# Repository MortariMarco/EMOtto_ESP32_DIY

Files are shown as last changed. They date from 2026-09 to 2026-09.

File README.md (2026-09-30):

# EMOtto ESP32 DIY — firmware 2.0

Robot project by Marco Mortari, for a classic ESP32 with Bluetooth Serial, GC9A01 display, four SG90 servos, two TTP223 touch sensors, VL53L0X and DFPlayer Mini.

Project and printable parts: https://www.printables.com/model/1362284-emotto_esp32-diy

## Start here

1. Download and extract the repository.
2. Install the Espressif ESP32 board support in Arduino IDE and select the board matching your classic ESP32.
3. Close Arduino IDE. Copy `Librerie/EMOttoDIYLib` and `Librerie/TFT_eSPI` into your Arduino sketchbook's `libraries` directory. Each copied folder must contain `library.properties` directly. Reopen Arduino IDE.
4. Install ESP32Servo, Adafruit GFX Library, Adafruit VL53L0X and DFRobotDFPlayerMini through Library Manager, including their dependencies.
5. Open **`Firmware/EMOttoESP32_2_0/EMOttoESP32_2_0.ino`**. Verify and upload. This is the full firmware; do not use the simplified Bluetooth example inside the library.
6. Install `App/EMOttoController_3_0.apk` on Android, pair the robot named `EMOtto`, and select it in the app.

Read [the Italian installation guide and pinout](LEGGIMI.md) before connecting or powering the robot.

## Included files

- Full Arduino firmware: `Firmware/EMOttoESP32_2_0/`.
- Original EMOttoDIYLib 1.0.0 and configured TFT_eSPI 2.5.43: `Librerie/`.
- Android APK and editable MIT App Inventor `.aia` source: `App/`.
- Audio files: `MicroSD/mp3/`.
- Wiring diagrams: `Collegamenti/`.
- Printable parts and documentation: see the corresponding folders.

The supplied TFT_eSPI is configured for GC9A01: MOSI 23, SCLK 18, CS 5, DC 17, RST 16, with TFT_BL 22 disabled. Avoid replacing it with a differently configured copy.

## App source

Import `App/EMOttoController_3_0.aia` into MIT App Inventor using Projects > Import project (.aia) from my computer. The Build menu can generate an Android APK. The `.aia` file is source code, not an installable app.

## Audio exclusions

Tracks **4, 31, 35, 36 and 37** are not distributed for copyright reasons. Do not renumber the remaining files. Use only audio you have the rights to use when completing your own microSD.

The original firmware uses DFPlayer `play(number)`, which selects a track index. Missing files or copy order can affect which sound is played; verify the mapping on your microSD. See `Documentazione/Audio_inclusi.csv` and the Italian guide.

## Verification status

This distribution preserves the supplied firmware and library sources. Archive integrity and the presence of the App Inventor project components were checked. No ESP32 compilation, app rebuild or hardware test was performed while preparing this package. Tested board/core/dependency versions are not recorded in the supplied archive; the author checklist is in `Documentazione/Verifica_autore.md`.

## Credits and licenses

EMOtto project by Marco Mortari. The custom library derives from Otto DIY; original library license files are preserved in their respective folders. The project credits Camilo Parra Palacio, Scotty Franzyshen and ElectronBot EMO. Components retain their respective licenses; this repository does not introduce one blanket license for all firmware, app, models and audio.

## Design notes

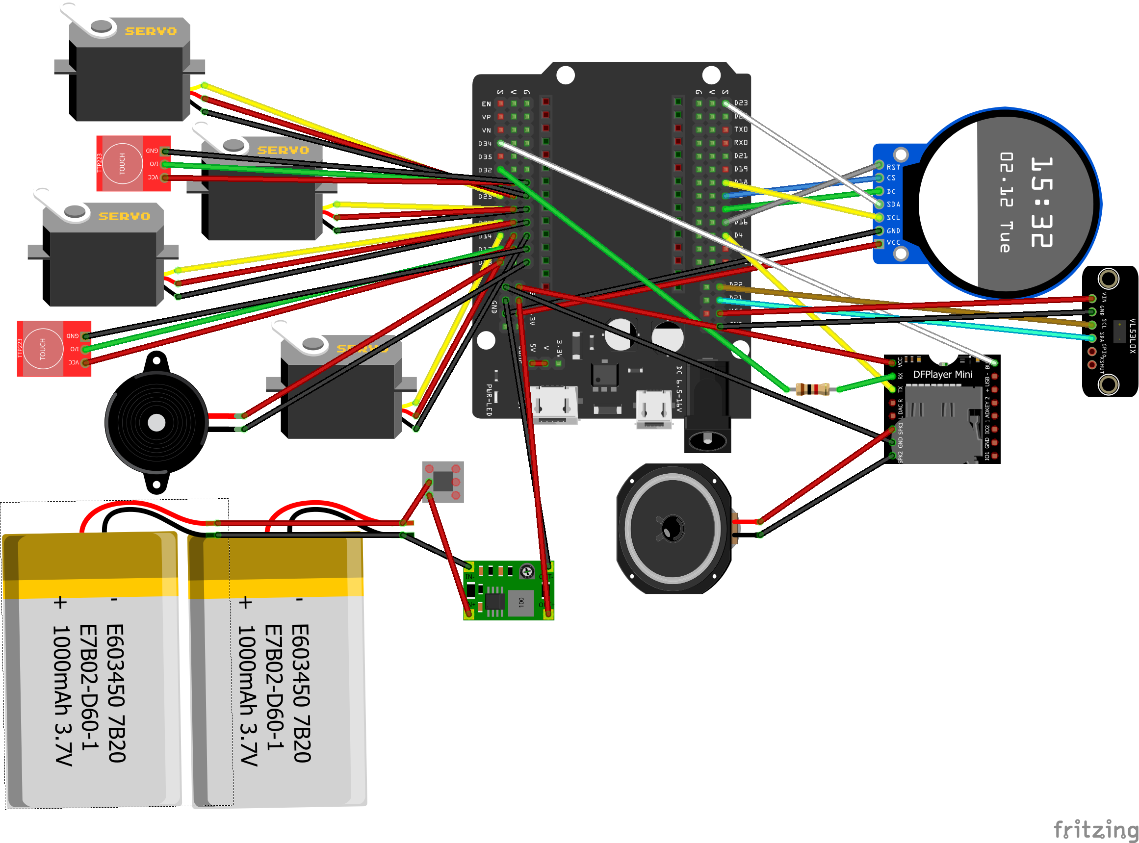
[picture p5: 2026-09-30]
Collegamenti/EMOtto_32_bb.png

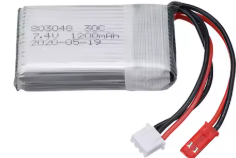
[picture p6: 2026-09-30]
Collegamenti/Battery 7,4V 1200mAh.png

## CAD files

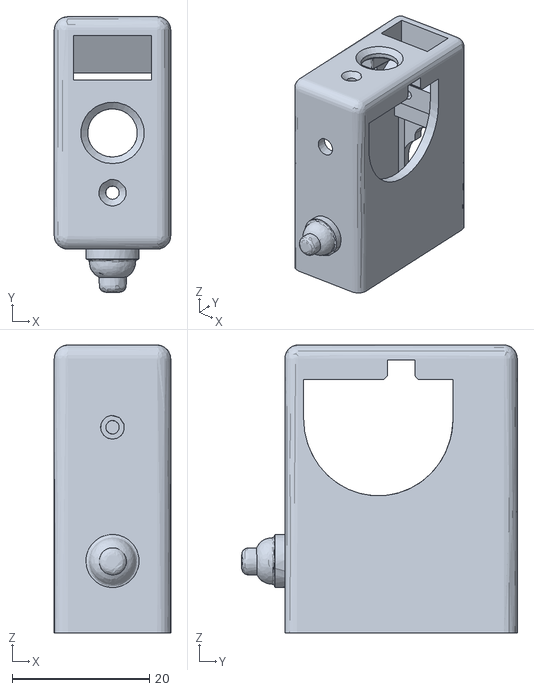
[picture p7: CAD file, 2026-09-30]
STL/EMOtto 2.0 ESP32_Leg.stl
17.0 x 40.2 x 42.0

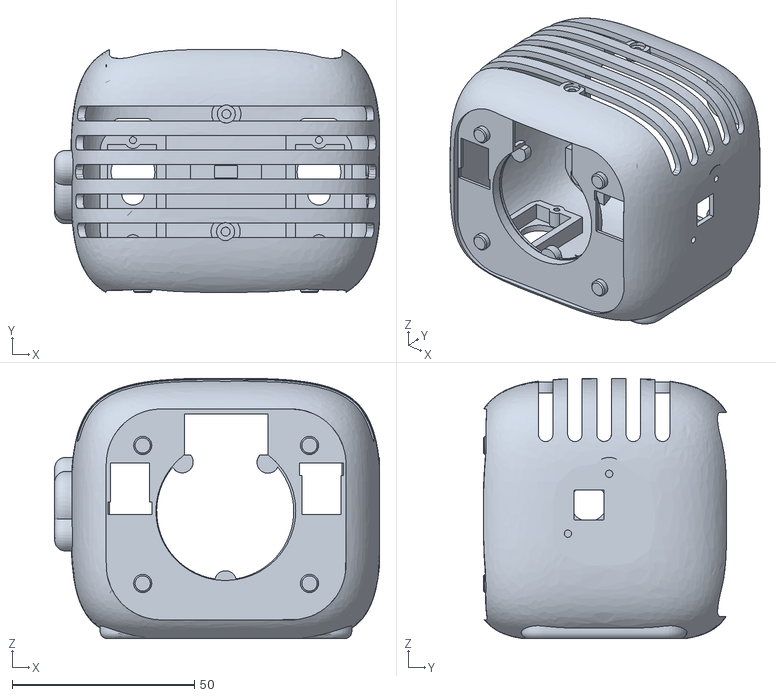
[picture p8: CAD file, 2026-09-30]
STL/EMOtto 2.0 ESP32_Head.stl
89.1 x 66.7 x 71.4

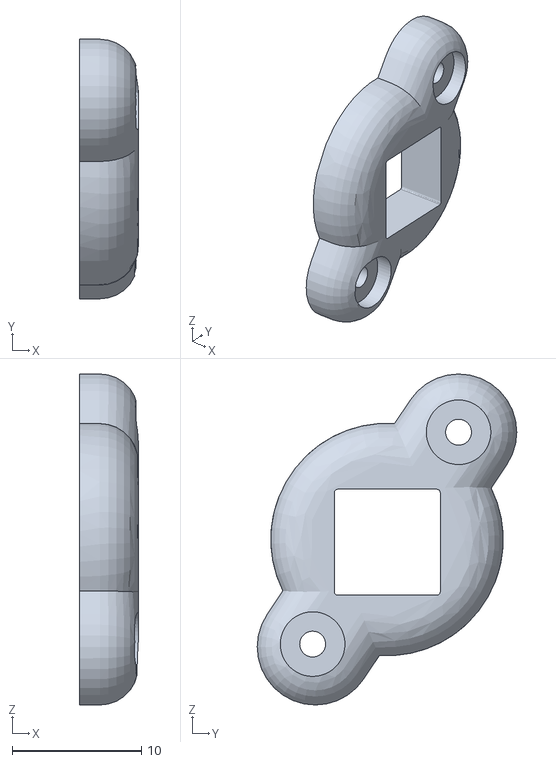
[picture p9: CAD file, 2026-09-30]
STL/EMOtto 2.0 ESP32_earswitch.stl
4.57 x 20.1 x 25.6

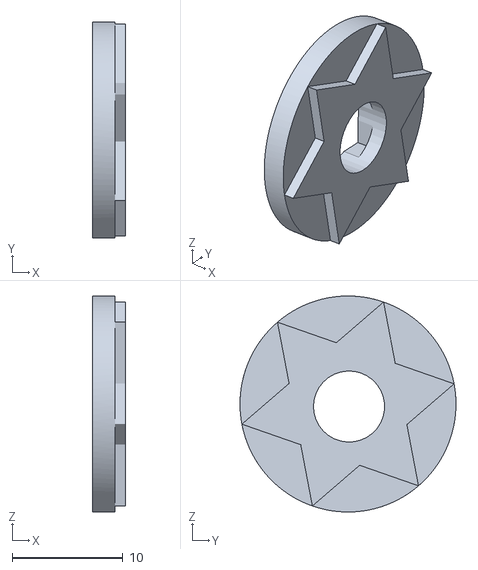
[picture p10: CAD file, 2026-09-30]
STL/EMOtto 2.0 ESP32_CoverEarSwitch.stl
3.01 x 19.5 x 19.5

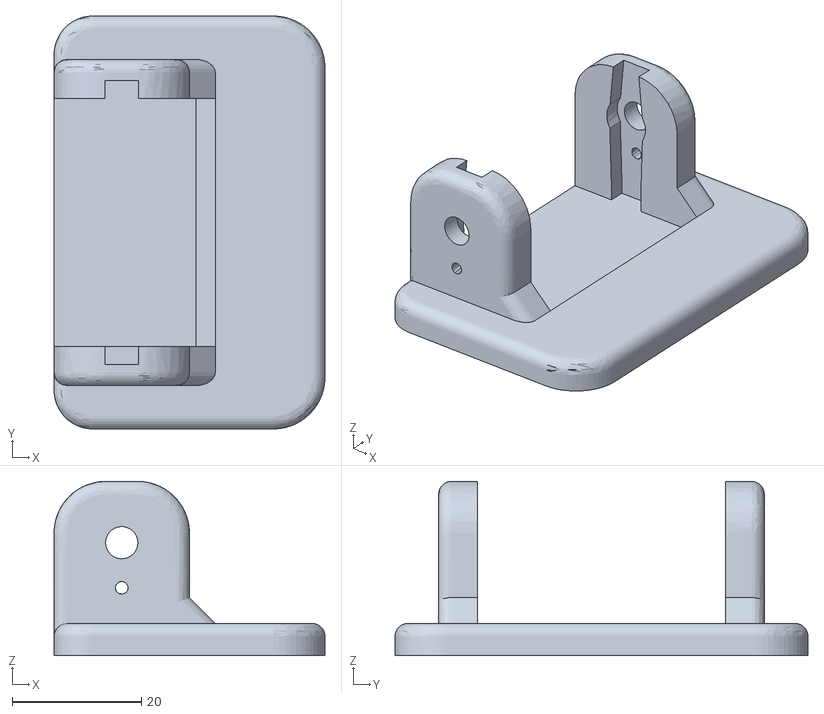
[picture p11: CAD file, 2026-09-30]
STL/EMOtto 2.0 ESP32_LeftFoot.stl
42.0 x 64.0 x 27.0

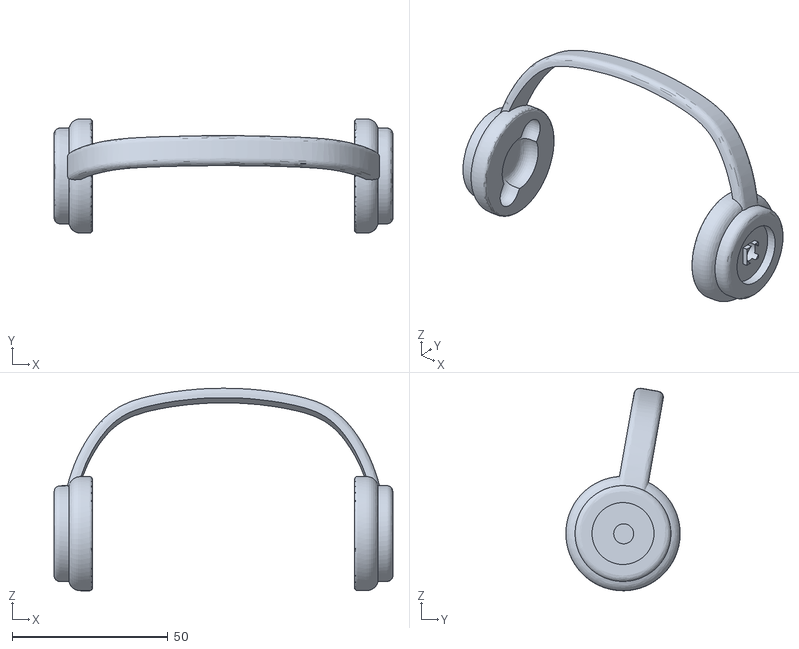
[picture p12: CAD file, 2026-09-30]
STL/EMOtto 2.0 ESP32_earphones.stl
108.8 x 36.7 x 65.0

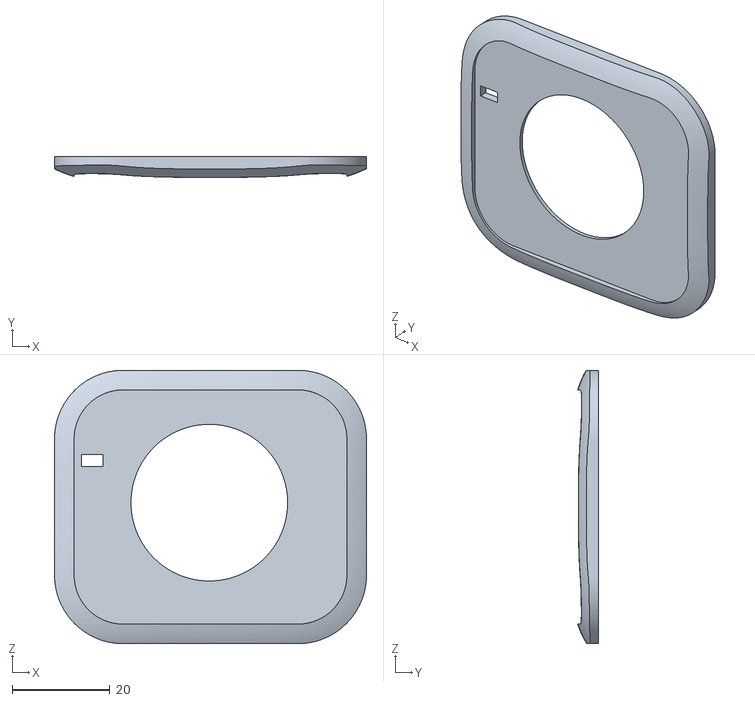
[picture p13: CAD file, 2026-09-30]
STL/EMOtto 2.0 ESP32_Front.stl
63.7 x 4.24 x 55.8

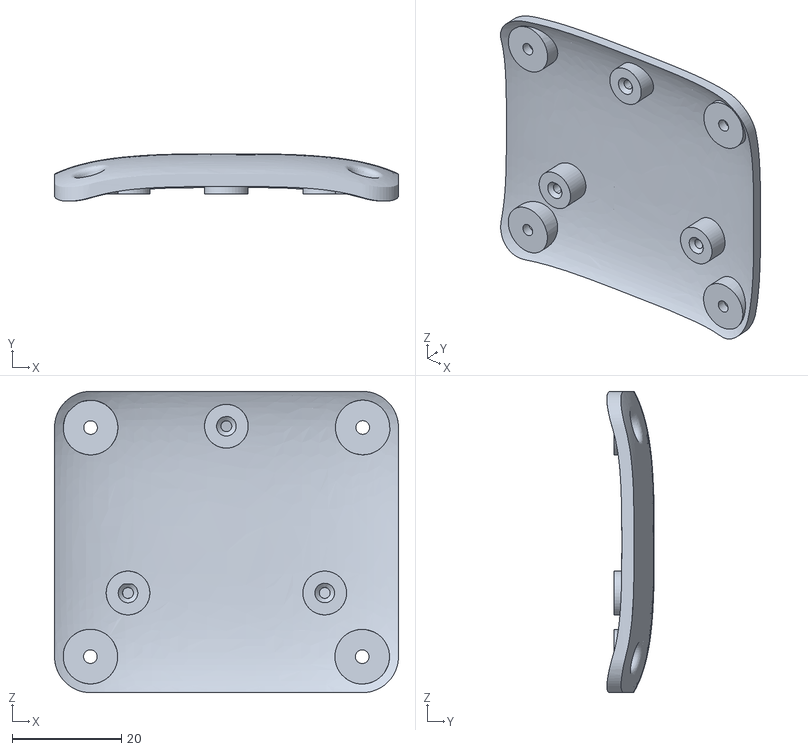
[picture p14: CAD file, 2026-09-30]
STL/EMOtto 2.0 ESP32_Back.stl
63.0 x 8.68 x 55.1

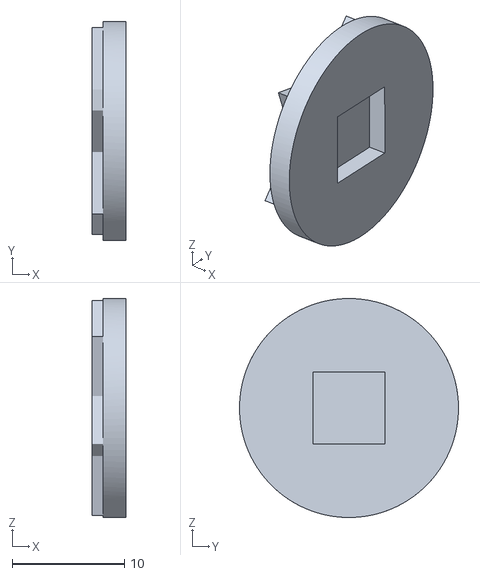
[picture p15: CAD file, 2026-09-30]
STL/EMOtto 2.0 ESP32_EarCover.stl
3.01 x 19.5 x 19.5

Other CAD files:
STL/EMOtto 2.0 ESP32_RightFoot.stl

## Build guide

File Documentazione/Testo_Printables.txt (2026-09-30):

EMOtto ESP32 2.0 — programma, librerie, app e file per il montaggio.

Estrarre lo ZIP e leggere LEGGIMI.md. Lo sketch da aprire è Firmware/EMOttoESP32_2_0/EMOttoESP32_2_0.ino. Nella distribuzione Printables scaricare EMOttoDIYLib.zip e TFT_eSPI.zip dagli allegati separati; nella distribuzione GitHub usare le cartelle Librerie. Installare le due librerie, quindi le dipendenze indicate nelle istruzioni. Nella cartella App sono inclusi l’APK da installare su Android e il progetto sorgente .aia da importare in MIT App Inventor per modificare l’app.

Le tracce musicali 4, 31, 35, 36 e 37 non sono distribuite per copyright. Per completare quelle funzioni usare personalmente audio di cui si possiedono i diritti, mantenendo gli abbinamenti del programma. Il firmware originale usa gli indici del DFPlayer: controllare l'ordine effettivo sulla microSD.

Sono inclusi schema dei collegamenti e STL. Scheda/versioni e risultati della prova sul robot devono essere riportati dall'autore prima di dichiarare questa distribuzione testata.

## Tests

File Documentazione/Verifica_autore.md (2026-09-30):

# Controlli per l'autore prima della pubblicazione

- Firmware, app, modelli, audio e librerie sono estratti dall'archivio fornito. Nessuna modifica ai sorgenti.
- Versioni di prova, vecchia OttoDIYLib, esempi semplificati, video, PSD e file duplicati non sono inclusi.
- EMOttoDIYLib 1.0.0 e TFT_eSPI 2.5.43 sono le copie originali.
- La libreria originale conserva il vecchio esempio Bluetooth: le istruzioni indicano esplicitamente di aprire il firmware principale, non quell'esempio.
- Le tracce 4, 31, 35, 36, 37 non sono incluse. play(numero) dipende dall'indice del DFPlayer: verificare gli abbinamenti audio e completare la microSD privata prima di dichiarare tutti i balli/canti funzionanti.
- Nello setup originale performExpression(EXP_NORMAL) chiama forceHome() prima di Otto.init(). Questo ordine è stato preservato per rispettare la richiesta di non cambiare il programma: verificare l'avvio sul robot; se occorre correggerlo, spostare l'espressione iniziale dopo Otto.init().
- Senza il VL53L0X rilevato lo setup entra in while(1): il sensore fa parte della configurazione richiesta.
- Incluso il progetto App Inventor .aia: archivio integro, Screen1 e blocchi Bluetooth presenti, asset grafici richiamati disponibili. Il progetto non è stato compilato; non è certificata la corrispondenza binaria con l’APK. Provare i pulsanti sul robot.
- Alcuni testi dei pulsanti nell’AIA includono i comandi `(`, `)` e `/`, che non hanno un case dedicato nel gestore Bluetooth della libreria. Questi controlli vanno verificati; app e firmware sono stati mantenuti come forniti.
- Le versioni esatte del core e delle dipendenze non sono registrate nell'archivio. Completare i dati qui sotto dopo la prova.

Scheda: ____________________
Arduino IDE: _______________
Core ESP32: ________________
ESP32Servo: ________________
Adafruit GFX: _____________
Adafruit VL53L0X: __________
DFRobotDFPlayerMini: _______
Data e risultato prova: ____

Aggiornamento del pacchetto: rimossi dall’elenco audio anche 0004 e 0036, aggiunto il progetto .aia alla documentazione. Il pacchetto contiene 32 file MP3. Nessuna modifica a firmware, librerie o sorgenti dell’app.

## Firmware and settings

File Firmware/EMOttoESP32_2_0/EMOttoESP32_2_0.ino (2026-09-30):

/// ---- EMOtto_ESP32_30pin + shield ver 2.0 ----- //
// ---- by Marco Mortari ---- //
// ---- ver 2.0 08/07/2025---- //
// ----  By Daddy for Francesco's Birthday 9 years---- //
// ---- Library EMOttoDIYLib 1.0.0 (OttoDIYLib 13.0.0.modificata)  ---- //
//--
//---------------------------------------------------------
// ---- Component  ---- //
// ---- 4 Servo SG90  180 Degrees ---- //
// ----  Round Display  GC9A01  ---- //
// ----  Passive Buzzer  ---- //
// ----  Touch Capacitive TTP223 * 2 ---- //
// ----  6 pin switch  ---- //
// ----  UBEC 5V 3A  ---- //
// ----  Battery 7.4V  ---- //
// ----  Sensor VL53L0X  ---- //
// ----  DFPlayer Mini  ---- //


//-- First step: Make sure the pins for servos are in the right position 
/*               -------- 
                |  (  )  |
                |--------|
 RIGHT LEG 26   |        | LEFT LEG 25
                 -------- 
                ||      ||
RIGHT FOOT 14 |---      ---| LEFT FOOT 27  
*/

// ----  GC9A01A LIBRERIA TFT_SPI SETUP200 CS=5 DC=17 RST= 16 SCLK=18 SDA(MOSI)=23 COMMENT BL=22---- //

// --- .ino
#include <EMOtto.h>
Otto Otto;  // This is Otto!
#include <TFT_eSPI.h>
#include <SPI.h>
#include "expressions.h"
#include "modes.h"
#include "sleep.h"
#include "draw_utils.h"
#include "colors.h"
#include "BluetoothCommands.h"
#include "BluetoothSerial.h"
#include <Adafruit_VL53L0X.h>
#include <DFRobotDFPlayerMini.h>
#include <modes.h>
#include "dance.h"
#include "dance2.h"
#include "dance3.h"
#include "dance4.h"

HardwareSerial mySerial(2);  // Serial2
BluetoothSerial SerialBT;
TFT_eSPI tft = TFT_eSPI(); // Usa impostazioni da User_Setup.h
Adafruit_VL53L0X lox = Adafruit_VL53L0X();
DFRobotDFPlayerMini myDFPlayer;

#define LeftLeg 25
#define RightLeg 26
#define LeftFoot 27
#define RightFoot 14
#define Buzzer 13
#define TOUCH_PIN_1 12  // Primo touch: cicla le emozioni
#define TOUCH_PIN_2 33  // Secondo touch: cambia modalità
// VL53L0X SCL=22
// VL53L0X SDA=21
//DFPlayer Mini su Serial2
// GPIO 32 (RX)
// GPIO 4 (TX)
//--- canzoni mp3 
// ─── DF-Player ────────────────────────────────────────────────────────────────
#define DF_BUSY_PIN     34          // indica che mp3 non e finito
bool  wasPlaying = false;           // stato precedente del BUSY (LOW = suona)
inline bool isPlaying() {           // helper: true quando il DFPlayer riproduce
return digitalRead(DF_BUSY_PIN) == LOW;
}

// --- STATO TOUCH --- //
bool touch1WasPressed = false;  // stato touch nel ciclo precedente TOUCH 1
bool touch2WasPressed = false;  // stato touch nel ciclo precedente TOUCH 2

// === PROTOTIPI delle funzioni ===
void drawExpression(int type);
void animateBlink();
void performExpression(int type);
void drawDance();
void dfPlay(uint16_t n) {         
  myDFPlayer.play(n);
}
// --- modalita operative --- //
const int totalModes = MODE_TOTAL;
ModeType currentMode = MODE_EMOTIONS;  // inizializza a modalità emotions
// Stato precedente dei touch
bool lastTouch1Pressed = false;
bool lastTouch2Pressed = false;
static unsigned long touchStartTime = 0;
static unsigned long lastTouch2Time = 0;
static unsigned long lastTouch1Time = 0;
const unsigned long debounceDelay = 150;  
// --- espressioni
ExpressionType expression = EXP_NORMAL;
const int totalExpressions = EXP_TOTAL - 1; 
ExpressionType lastExpression = EXP_NORMAL;
//---- pupille
int pupilOffsetX = 0;
int pupilOffsetY = 0;
//---palpebre---//
unsigned long lastBlinkTime = 0;
unsigned long blinkInterval = 4000;  // ogni quanti ms far partire un blink spontaneo
bool isBlinking = false;
int blinkStep = 0;
// ---- ADDORMENTAMENTO  ----//
unsigned long sleepTimeout = 90000;  // 90 secondi DOPO QUANTO SI ADDORMENTA
unsigned long lastActivityTime = 0;
bool isSleeping = false;
SleepState sleepState = SLEEP_START;
unsigned long sleepTimer = 0;
int breathRadius = 8;
int zCount = 0;
//----lacrime ----//
// Variabili per animazione lacrime con esplosione
int tearY = 122;
int tearStartY = 122;
int tearEndY = 160;
unsigned long lastTearTime = 0;
int tearSpeed = 50;
bool tearJustStarted = true;
bool tearVisible = true;
bool tearExploding = false;
int explosionStep = 0;
int maxExplosionSteps = 4;
// --lacrimuccia
bool yawnRunning = false;     // indica se l’animazione sbadiglio è in corso
unsigned long yawnStartTime = 0;
int yawnPhase = 0;            // fasi dell’animazione sbadiglio
bool yawnTearActive = false;
int yawnTearY = 0;
unsigned long lastYawnTearUpdate = 0;
// -- battiti cuore --//
// Impostazioni animazione battito cuore
unsigned long lastHeartbeatTime = 0;
int heartbeatIndex = 0;
int heartbeatSizes[] = { 12, 16, 14, 13, 12 };      // battito veloce poi lento
int heartbeatDelays[] = { 50, 80, 120, 150, 200 };  // ritmi variabili
int numHeartbeatFrames = sizeof(heartbeatSizes) / sizeof(int);
bool isInLove = false;           // controlla se animare
// --- bluetooth --- ///
bool wasConnected = false;
bool lastBluetoothState = false;
static bool wasSleepingConnected = false;
// --- DANCE background ---
static uint32_t lastDanceBgTime = 0;
const uint32_t danceBgInterval = 300;   // ms cambio colore
// --- cantando
unsigned long lastFootMoveTime = 0;
bool footDown = false;
unsigned long footInterval = 600;  // battito ogni 600 ms (~100 BPM)
int currentSong = -1;
bool songStarted = false;
int lastSongPlayed = -1;
int MP3_MIN = 31;
int MP3_MAX = 34;
bool singerIntroDone = false;
unsigned long singerIntroStart = 0;
enum SingerState { INTRO_29, BASE_30, MAIN_SONG };
SingerState singerState = INTRO_29;
extern ModeType       currentMode;
extern ExpressionType lastExpression;
ModeType lastPrintedMode = static_cast<ModeType>(-1);
// balli
extern bool dance2Active ;
extern bool musicFinished ;
extern bool musicStarted ;
extern bool dance3Active ;
extern bool music3Finished ;
extern bool music3Started ;
extern bool dance4Active ;
extern bool music4Finished ;
extern bool music4Started ;
// --- Volume dfplayer 
int currentVolume = 25;
// velocita iniziale
int walkSpeed = 1000;

void setup() {
  Serial.begin(115200);  
  tft.init();
  tft.setRotation(2);
   performExpression(EXP_NORMAL);   // volto iniziale 
  lastExpression = EXP_NORMAL;
 // --- CANTANTE
 //initMusicalNotes();
  // Inizializza I2C sui pin specifici
  Wire.begin(21, 22);  // SDA = 21, SCL = 22
  if (!lox.begin()) {
    Serial.println("VL53L0X non trovato!");
    while (1);
  }
  Serial.println("VL53L0X pronto");
  randomSeed(micros());
  lastActivityTime = millis();
  Otto.init(LeftLeg, RightLeg, LeftFoot, RightFoot, true, Buzzer);
  Otto.sing(S_connection);
  // --- Bluetooth  ----//
  SerialBT.begin("EMOtto");
  Serial.println("Bluetooth avviato. Ora puoi accoppiare!");
  // ----- DFPlayer Mini ---- //
  // Avvia Serial2 su GPIO 32 (RX), GPIO 4 (TX)
  mySerial.begin(9600, SERIAL_8N1, 32, 4);
  if (!myDFPlayer.begin(mySerial)) {
    Serial.println(" DFPlayer non trovato! Disabilitato.");
  } else {
    Serial.println("✅ DFPlayer inizializzato correttamente.");
    myDFPlayer.volume(currentVolume);
    delay(500);  // piccolo delay per sicurezza
      myDFPlayer.EQ(DFPLAYER_EQ_NORMAL);
    myDFPlayer.play(1);
  }
  pinMode(TOUCH_PIN_1, INPUT_PULLDOWN);
  touch1WasPressed = digitalRead(TOUCH_PIN_1) == HIGH;
  pinMode(TOUCH_PIN_2, INPUT);
  touch2WasPressed = digitalRead(TOUCH_PIN_2) == HIGH;
  pinMode(DF_BUSY_PIN, INPUT_PULLUP);   // BUSY: HIGH = fermo, LOW = suona
  forceHome();
  // velocita iniziale
   walkSpeed = 1000;
   // Stati bluetooth
//    SerialBT.print("SPD:");
// SerialBT.println(walkSpeed);

// SerialBT.print("VOL:");
// SerialBT.println(currentVolume);

}

void loop() {
  unsigned long now = millis();
  bool touch1Pressed = digitalRead(TOUCH_PIN_1) == HIGH;
  bool touch2Pressed = digitalRead(TOUCH_PIN_2) == HIGH;
  // --- SLEEP MODE ---
  if (isSleeping) {
    updateSleepingAnimation();
    if ((touch1Pressed || touch2Pressed) && !touch1WasPressed && !touch2WasPressed) {
      touchStartTime = now;
    }
    if (!(touch1Pressed || touch2Pressed) && (touch1WasPressed || touch2WasPressed)) {
      wakeUp();
    }
    //  Risveglio tramite connessione Bluetooth
    if (SerialBT.connected()) {
      wakeUp();
    }
   touch1WasPressed = touch1Pressed;
   touch2WasPressed = touch2Pressed;
     return;
  }
  // --- ENTRA IN SLEEP SE INATTIVO ma solo se è in modalita emotions---
  if (!isSleeping
      && (now - lastActivityTime > sleepTimeout)
      && currentMode != MODE_AVOID
      && currentMode != MODE_FOLLOW
      && currentMode != MODE_DANCE
      && currentMode != MODE_SINGER
      && !SerialBT.hasClient()) {
    Serial.println(">> Condizione SLEEP soddisfatta");
    enterSleepMode();
    return;
  }
  // --- GESTIONE TOUCH 1: cambio espressione solo in modalità emozioni ---
  if (touch1Pressed && !touch1WasPressed && !isBlinking && currentMode == MODE_EMOTIONS && (now - lastTouch1Time > debounceDelay)) {
    lastTouch1Time = now;
    ExpressionType next = static_cast<ExpressionType>((expression + 1) % (totalExpressions + 1));
    Otto.sing(S_buttonPushed);
    performExpression(next);      // disegna + audio + movimento
    lastExpression   = next;
    lastActivityTime = now;
  }
  // --- GESTIONE TOUCH 2: cambio modalità ---
  if (touch2Pressed && !touch2WasPressed && (now - lastTouch2Time > debounceDelay)) {
    lastTouch2Time = now;
   if (currentMode == MODE_SINGER) {          // stop “d’emergenza”
    Serial.println(F(">> TOUCH2: esco da SINGER"));
    exitSingerMode(); 
    return;                                   // fine loop, niente altro da fare
  }
   if (currentMode == MODE_DANCE) {
        Serial.println(">> TOUCH2 premuto: fermo musica e movimenti (da DANCE)");
        myDFPlayer.stop();
        Otto.home();
        stopDance();
        songStarted = false;
        // 🔁 PASSA ALLA MODALITÀ SINGER
        currentMode = MODE_SINGER;
        lastExpression = EXP_NONE;
        Serial.println("Passo a modalità SINGER");
        return;
    }
    // Modalità normali: scorre ciclicamente
  /* --- ciclo modalità (EMOTIONS→…→SINGER→EMOTIONS) --- */
 currentMode = static_cast<ModeType>((currentMode + 1) % MODE_TOTAL);
    Serial.print(F(">> Cambio modalità: "));
    Serial.println(currentMode);
    // aggiorna stampa modalità subito dopo il cambio (opzionale)
    lastPrintedMode = static_cast<ModeType>(-1); // forza ristampa
   return;
}
  // --- STAMPA MODALITÀ SOLO SE CAMBIATA ---
  if (currentMode != lastPrintedMode) {
    switch (currentMode) {
      case MODE_AVOID: Serial.println("AVOID"); break;
      case MODE_FOLLOW: Serial.println("FOLLOW"); break;
      case MODE_DANCE: Serial.println("DANCE"); break;
      case MODE_SINGER: Serial.println("SINGER"); break;
      case MODE_EMOTIONS: Serial.println("EMOTIONS"); break;
    }
    lastPrintedMode = currentMode;
  }
  //  lastActivityTime = now;
  // Aggiorna stato precedente TOCCHI
  touch1WasPressed = touch1Pressed;
  touch2WasPressed = touch2Pressed;
  // --- verifica accoppiamento bluetooth ---///
  bool currentlyConnected = SerialBT.hasClient();
  if (currentlyConnected && !wasConnected) {
    // Appena connesso
    Serial.println("✅ Bluetooth connesso!");
    showBluetoothOn(expression);  // Mostra icona on alla connessione
    myDFPlayer.play(13); //modalita bluetooth attivata 
  } else if (!currentlyConnected && wasConnected) {
    showBluetoothOff(expression);  // Mostra icona off alla connessione
    Serial.println("❌ Bluetooth disconnesso!");
 //   myDFPlayer.play(13); //modalita bluetooth disattivata 
  }
  wasConnected = currentlyConnected;

  // --- GESTIONE MODALITÀ ---
    switch (currentMode) {
    case MODE_AVOID:
      if (lastExpression != EXP_AVOID) {
        performExpression(EXP_AVOID);
        lastExpression = EXP_AVOID;
      }
      handleAvoidMode();
      break;
    case MODE_FOLLOW:
      if (lastExpression != EXP_FOLLOW && !isBlinking) {
        performExpression(EXP_FOLLOW);
        lastExpression = EXP_FOLLOW;
      }
      handleFollowMode();
      break;
    case MODE_DANCE:
      if (currentMode != MODE_DANCE) break;  // Protezione extra
       if (lastExpression != EXP_DANCE && !isBlinking) {
        updateDance();      // gestisce passi
        performExpression(EXP_DANCE);   // Avvia danza
        lastExpression = EXP_DANCE;
 }
        updateDance();      // ballo attivo
        handleDanceMode();
        break; 
     case MODE_SINGER: {
   /* ── Primo ingresso ── */
       if (lastExpression != EXP_SINGER && !isBlinking) {
        performExpression(EXP_SINGER);      // faccina cantante
        lastExpression = EXP_SINGER;
        singerState = INTRO_29;
        startSingerFoot();                  // tuoi passi di ballo
        dfPlay(29);                         // intro vocale
  }
         drawSingingMouth();
         updateSingerFoot();
  /* ── Avanzamento stati con BUSY ── */
  switch (singerState) {
    case INTRO_29:
      if (!isPlaying() && wasPlaying) {     // 29 terminata
        dfPlay(30);                         // base musicale
        singerState = BASE_30;
      }
        break;

    case BASE_30:
      if (!isPlaying() && wasPlaying) {     // 30 terminata
        playRandomSong();                   // tua routine
        singerState = MAIN_SONG;
      }
      break;

    case MAIN_SONG:
      if (!isPlaying() && wasPlaying) {     // brano finito
        exitSingerMode();
      }
      break;
  }
  /* ── Salva stato BUSY per il prossimo loop ── */
  wasPlaying = isPlaying();
  break;
}
     case MODE_EMOTIONS:
       if (expression != lastExpression && !isBlinking) {
        performExpression(expression);
        lastExpression = expression;
  }
    break;
     default:
    break;
    }
   // --- ANIMAZIONE BLINK ---
  if (!isBlinking && (now - lastBlinkTime > blinkInterval)) {
    isBlinking = true;
    blinkStep = 0;
  }
  if (isBlinking) {
    animateBlink();
  }
  if ((expression == EXP_LOVE || expression == EXP_FOLLOW)   // ❤ anche in follow
    && !isBlinking
    && !isSleeping) {
    updateHeartEyes();
  }
  // --- ANIMAZIONE LACRIME ---
  if (expression == EXP_SAD && !isBlinking && !isSleeping) {
    updateTears();
  }
  // --- LACRIMUCCIA POST-SBADIGLIO ---
// Chiamare updateYawnAnimation() ogni ciclo
updateYawnAnimation();
// Chiamare updateYawnTear() per animazione lacrima
updateYawnTear();
// --- Sfondo cangiante mentre balla ---
if (expression == EXP_DANCE && millis() - lastDanceBgTime > danceBgInterval && !isBlinking) {
  tft.fillScreen(nextPastelColor());
    drawDance();
  lastDanceBgTime = millis();
}
 // --- riceve comandi bluetooth --- //
  handleBluetoothCommands(SerialBT, expression, currentMode, lastActivityTime);
  updateWalking();
 // richiamo balli
if (dance2Active) {
  updateDance2();
  updateMusic2Status();
}
  if (danceStep != STEP_NONE && !musicFinished) {
    updateDance();
  }
if (dance3Active) {
  updateDance3();
  updateMusic3Status();
}
if (dance4Active) {
  updateDance4();
  updateMusic4Status();
}

}
// --- Fine Loop --- //
// *******************  FUNZIONI DI SUPPORTO  ******************* //
void forceHome() {
  Otto.attachServos();
  int homes[4] = { 90, 90, 90, 90 };
  Otto._moveServos(500, homes);  // Muove forzatamente, bypassa Otto.home()
  delay(700);
  Otto.detachServos();
  Otto.setRestState(true);  // Mantieni coerenza col flag
}

void handleAvoidMode() {
  VL53L0X_RangingMeasurementData_t measure;
  lox.rangingTest(&measure, false);
  if (measure.RangeStatus != 4) {
    int distanza = measure.RangeMilliMeter;
    Serial.print("AVOID - Distanza: ");
    Serial.println(distanza);
  if (distanza < 150) {
    drawExpression(EXP_ANGRY);
      Otto.walk(2, 1000, -1);  // BACKWARD x2
      Otto.turn(3, 1000, 1);   // LEFT x3
    }
    Otto.walk(1, 1000, 1);  // FORWARD x1
  }
}

void handleFollowMode() {
  VL53L0X_RangingMeasurementData_t measure;
  lox.rangingTest(&measure, false);
  if (measure.RangeStatus != 4) {
    int distanza = measure.RangeMilliMeter;
    Serial.print("FOLLOW - Distanza: ");
    Serial.println(distanza);
  if (distanza > 180 && distanza < 600) {
      Otto.walk(1, 1000, 1);  // cammina avanti
    } else {
      //     Otto.stop();
      drawExpression(EXP_NORMAL);
    }
  }
}

void handleDanceMode() {
  // sfondo cangiante
  if (millis() - lastDanceBgTime > danceBgInterval && !isBlinking) {
        tft.fillScreen(nextPastelColor()); // sfondo nuovo
    drawDance();   
    lastDanceBgTime = millis();
  }
}

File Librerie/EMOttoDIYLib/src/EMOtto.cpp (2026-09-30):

#if defined(ARDUINO) && ARDUINO >= 100
  #include "Arduino.h"
#else
  #include "WProgram.h"
  #include <pins_arduino.h>
#endif
#include "EMOtto.h"
#include <Oscillator.h>

void Otto::init(int YL, int YR, int RL, int RR, bool load_calibration, int Buzzer) {

  servo_pins[0] = YL;
  servo_pins[1] = YR;
  servo_pins[2] = RL;
  servo_pins[3] = RR;

  attachServos();
  isOttoResting=false;

  if (load_calibration) {
    for (int i = 0; i < 4; i++) {
      int servo_trim = EEPROM.read(i);
      if (servo_trim > 128) servo_trim -= 256;
      servo[i].SetTrim(servo_trim);
    }
  }

  //Buzzer pin:
  pinBuzzer = Buzzer;
  pinMode(Buzzer,OUTPUT);
 
}
///////////////////////////////////////////////////////
void Otto::initMATRIX(int DIN, int CS, int CLK, int rotate){
ledmatrix.init( DIN, CS, CLK, 1, rotate);   // set up Matrix display
}
void Otto::matrixIntensity(int intensity){
ledmatrix.setIntensity(intensity);
}

///////////////////////////////////////////////////////////////////
//-- ATTACH & DETACH FUNCTIONS ----------------------------------//
///////////////////////////////////////////////////////////////////
void Otto::attachServos(){
    servo[0].attach(servo_pins[0]);
    servo[1].attach(servo_pins[1]);
    servo[2].attach(servo_pins[2]);
    servo[3].attach(servo_pins[3]);
}

void Otto::detachServos(){
    servo[0].detach();
    servo[1].detach();
    servo[2].detach();
    servo[3].detach();
}

///////////////////////////////////////////////////////////////////
//-- OSCILLATORS TRIMS ------------------------------------------//
///////////////////////////////////////////////////////////////////
void Otto::setTrims(int YL, int YR, int RL, int RR) {
  servo[0].SetTrim(YL);
  servo[1].SetTrim(YR);
  servo[2].SetTrim(RL);
  servo[3].SetTrim(RR);
}

void Otto::saveTrimsOnEEPROM() {

  for (int i = 0; i < 4; i++){
      EEPROM.write(i, servo[i].getTrim());
  }
}

///////////////////////////////////////////////////////////////////
//-- BASIC MOTION FUNCTIONS -------------------------------------//
///////////////////////////////////////////////////////////////////
void Otto::_moveServos(int time, int  servo_target[]) {

  attachServos();
  if(getRestState()==true){
        setRestState(false);
  }

  final_time =  millis() + time;
  if(time>10){
    for (int i = 0; i < 4; i++) increment[i] = (servo_target[i] - servo[i].getPosition()) / (time / 10.0);

    for (int iteration = 1; millis() < final_time; iteration++) {
      partial_time = millis() + 10;
      for (int i = 0; i < 4; i++) servo[i].SetPosition(servo[i].getPosition() + increment[i]);
      while (millis() < partial_time); //pause
    }
  }
  else{
    for (int i = 0; i < 4; i++) servo[i].SetPosition(servo_target[i]);
    while (millis() < final_time); //pause
  }

  // final adjustment to the target. if servo speed limiter is turned on, reaching to the goal may take longer than 
  // requested time.
  bool f = true;
  while(f) {
    f = false;
    for (int i = 0; i < 4; i++) {
      if (servo_target[i] != servo[i].getPosition()) {
        f = true;
        break;
      }
    }
    if (f) {
      for (int i = 0; i < 4; i++) {
        servo[i].SetPosition(servo_target[i]);
      }
      partial_time = millis() + 10;
      while (millis() < partial_time); //pause
    }
  };
}

void Otto::_moveSingle(int position, int servo_number) {
if (position > 180) position = 90;
if (position < 0) position = 90;
  attachServos();
  if(getRestState()==true){
        setRestState(false);
  }
int servoNumber = servo_number;
if (servoNumber == 0){
  servo[0].SetPosition(position);
}
if (servoNumber == 1){
  servo[1].SetPosition(position);
}
if (servoNumber == 2){
  servo[2].SetPosition(position);
}
if (servoNumber == 3){
  servo[3].SetPosition(position);
}
}

void Otto::oscillateServos(int A[4], int O[4], int T, double phase_diff[4], float cycle=1){

  for (int i=0; i<4; i++) {
    servo[i].SetO(O[i]);
    servo[i].SetA(A[i]);
    servo[i].SetT(T);
    servo[i].SetPh(phase_diff[i]);
  }
  double ref=millis();
   for (double x=ref; x<=T*cycle+ref; x=millis()){
     for (int i=0; i<4; i++){
        servo[i].refresh();
     }
  }
}

void Otto::_execute(int A[4], int O[4], int T, double phase_diff[4], float steps = 1.0){

  attachServos();
  if(getRestState()==true){
        setRestState(false);
  }


  int cycles=(int)steps;

  //-- Execute complete cycles
  if (cycles >= 1)
    for(int i = 0; i < cycles; i++)
      oscillateServos(A,O, T, phase_diff);

  //-- Execute the final not complete cycle
  oscillateServos(A,O, T, phase_diff,(float)steps-cycles);
}

///////////////////////////////////////////////////////////////////
//-- HOME = Otto at rest position -------------------------------//
///////////////////////////////////////////////////////////////////
void Otto::home(){

  if(isOttoResting==false){ //Go to rest position only if necessary

    int homes[4]={90, 90, 90, 90}; //All the servos at rest position
    _moveServos(500,homes);   //Move the servos in half a second

    detachServos();
    isOttoResting=true;
  }
}

bool Otto::getRestState(){
    return isOttoResting;
}

void Otto::setRestState(bool state){

    isOttoResting = state;
}

///////////////////////////////////////////////////////////////////
//-- PREDETERMINED MOTION SEQUENCES -----------------------------//
///////////////////////////////////////////////////////////////////
//-- Otto movement: Jump
//--  Parameters:
//--    steps: Number of steps
//--    T: Period
//---------------------------------------------------------
void Otto::jump(float steps, int T){

  int up[]={90,90,150,30};
  _moveServos(T,up);
  int down[]={90,90,90,90};
  _moveServos(T,down);
}

//---------------------------------------------------------
//-- Otto gait: Walking  (forward or backward)
//--  Parameters:
//--    * steps:  Number of steps
//--    * T : Period
//--    * Dir: Direction: FORWARD / BACKWARD
//---------------------------------------------------------
void Otto::walk(float steps, int T, int dir){
  //-- Oscillator parameters for walking
  //-- Hip sevos are in phase
  //-- Feet servos are in phase
  //-- Hip and feet are 90 degrees out of phase
  //--      -90 : Walk forward
  //--       90 : Walk backward
  //-- Feet servos also have the same offset (for tiptoe a little bit)
  int A[4]= {30, 30, 20, 20};
  int O[4] = {0, 0, 4, -4};
  double phase_diff[4] = {0, 0, DEG2RAD(dir * -90), DEG2RAD(dir * -90)};

  //-- Let's oscillate the servos!
  _execute(A, O, T, phase_diff, steps);
}
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

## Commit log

2026-09-30 Add EMOtto ESP32 DIY project overview
2026-09-30 Publish complete EMOtto ESP32 DIY 2.0 project with firmware, libraries, app sources and assembly files
    [Audio_inclusi.csv, Configuring options.txt, EMOtto 2.0 ESP32_Back.stl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]
